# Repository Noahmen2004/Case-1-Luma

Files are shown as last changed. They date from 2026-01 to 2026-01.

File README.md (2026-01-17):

# Case-1-Luma
Case 1: Luma ontwerp slimme producten Ugent

# LUMA - Slim Fietsverlichtingssysteem

**Deze repository bevat de volledige broncode, specifiek geoptimaliseerd voor de Arduino Nano.**

**LUMA** is een geavanceerd, modulair en zelfvoorzienend verlichtingssysteem voor fietsen. Het combineert veiligheid met een duurzame, gerecyclede stroomvoorziening. Het systeem beschikt over dynamische richtingaanwijzers ("Audi-stijl"), een smelheids gestuurd remlicht en een unieke opstartanimatie.

Wat LUMA uniek maakt, is het **hybride stroomsysteem**: een hergebruikte DC-motor (uit een oude schuurmachine) fungeert als krachtige dynamo. Een speciaal circuit met een **buffercondensator** stabiliseert de energie om de centrale powerbank op te laden, die vervolgens de verlichting voedt en je smartphone kan opladen via USB-C.

## Functionaliteiten

### 1. Slimme Verlichting
* **Achterlicht (Matrix 3x12):**
    * **Rijden:** Gedimd rood licht.
    * **Vertragen (Uitbollen):** Licht op naar medium rood (gedetecteerd via accelerometer).
    * **Remmen:** Fel rood remlicht.
    * **Noodstop:** Knipperend rood licht (strobe) bij hard remmen.
* **Voorlicht (Matrix 3x8 + PowerLEDs):**
    * **Dagrijverlichting (DRL):** Witte LED-matrix voor zichtbaarheid.
    * **Koplamp:** 4x High Power LEDs voor zicht in het donker (geschakeld via MOSFET).
* **Richtingaanwijzers:**
    * Dynamische "Wipe" animatie (Oranje) die van binnen naar buiten loopt.

### 2. Modulair & Waterdicht Ontwerp
* **Waterdichte Connectoren:** Het systeem maakt gebruik van hoogwaardige IP68 connectoren (YETOR). Hierdoor is de opstelling volledig modulair: lampen en knoppen kunnen eenvoudig worden losgekoppeld of vervangen.
* **3D Geprinte Behuizing:** Op maat gemaakte behuizingen met **TPU-afdichtingen** zorgen ervoor dat de elektronica in alle weersomstandigheden droog blijft.

### 3. DIY Hybrid Power (Upcycled Dynamo)
* **Custom Generator:** Een DC-motor uit een oude schuurmachine is gemonteerd als wrijvingsdynamo.
* **Stabiele Stroom:** Een circuit met een grote **buffercondensator** vlakt het fluctuerende signaal van de motor af tot een constante 5V-lading voor de powerbank.
* **Phone Charging:** Geïntegreerde USB-C uitgang aan het stuur om je telefoon op te laden tijdens het fietsen.

## Hardware & Componenten

### Elektronica
* **Microcontroller:** Arduino Nano (Code in `/code`).
* **Sensor:** MPU-6050 Accelerometer (Op zijn zijkant gemonteerd).
* **Generator:** DC Motor (Gerecycled uit schuurmachine).
* **Power Conditioning:** Buffercondensator.
* **Opslag:** Powerbank met pass-through charging support.
* **LEDs:** WS2812B Strips + 4x High Power LEDs.
* **Bediening:** 3x R16-503 Latching Drukknoppen met LED-feedback.

### Connectiviteit
We gebruiken **YETOR Waterdichte Connectoren** om de centrale unit met de randapparatuur te verbinden.
* **Product:** [YETOR Waterdichte Draadconnectoren (Amazon)](https://www.amazon.nl/YETOR-waterdichte-draadconnectoren-vrachtwagen-draadverbindingen/dp/B07S7J85BT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)

## 3D Onderdelen (STL Bestanden)

Alle printbare onderdelen zijn te vinden in de map 3D- onderdelen. Het systeem maakt gebruik van een universele "Rekker & Haak" montagemethode.

### 1. Verlichtingsmodules
* Licht houder: Behuizing waar de LED-matrix in past.
* Licht lens: Transparante lens voor lichtdiffusie die op de houder klikt.

### 2. Centrale Control Unit
* Behuizing dynamo en powerbank: Behuizing voor de Arduino Nano, PCB en Powerbank.
* Dichtingsring: Een flexibele dichtingsring (**Print in TPU**) voor het waterdicht maken van de deksel.

### 3. DIY Dynamo Systeem
* Dynamo houder: Robuuste klem om de schuurmachine-motor aan de voor- of achtervork te bevestigen.
* Dynamo wiel: Een wrijvingswiel dat op de as van de DC-motor wordt geperst om contact te maken met de fietsband.

### 4. Bediening & Montage
* Knoppen behuizing: Behuizing voor de 3 knoppen aan het stuur.
* Bevestigings haak: Universele haak voor het montagesysteem.
* Aanpasbare rekker: Een flexibele, verstelbare rekker (**Print in TPU**) die om het fietsframe spant en in de haak grijpt.

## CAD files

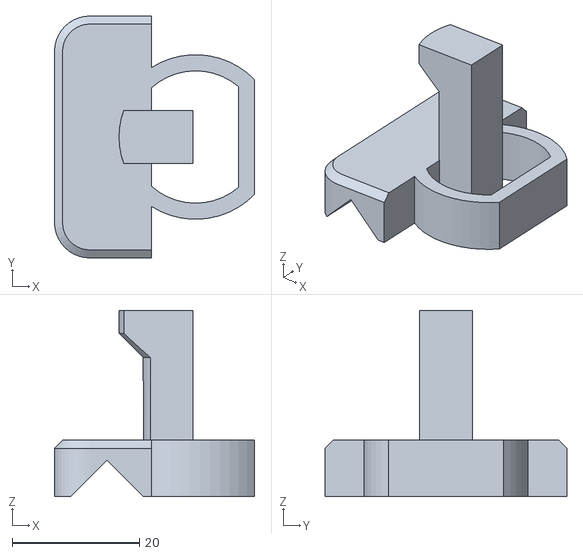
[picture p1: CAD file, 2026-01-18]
3D-onderdelen/GSM houder slider.stl
31.5 x 38.1 x 29.3

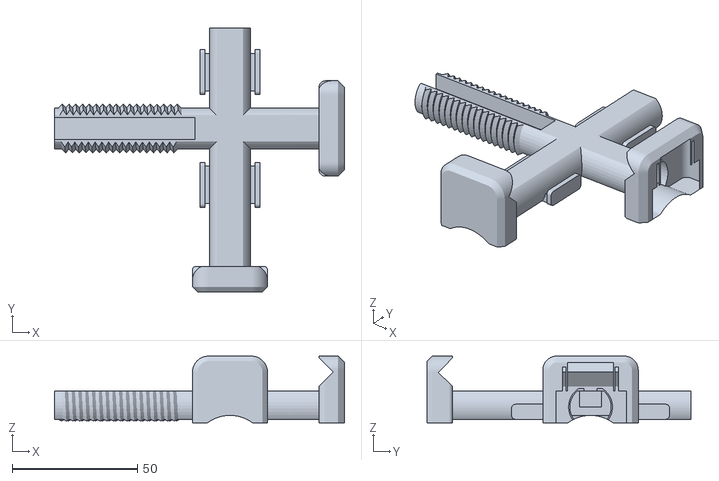
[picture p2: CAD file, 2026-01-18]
3D-onderdelen/GSM houder.stl
115.7 x 105.2 x 26.7

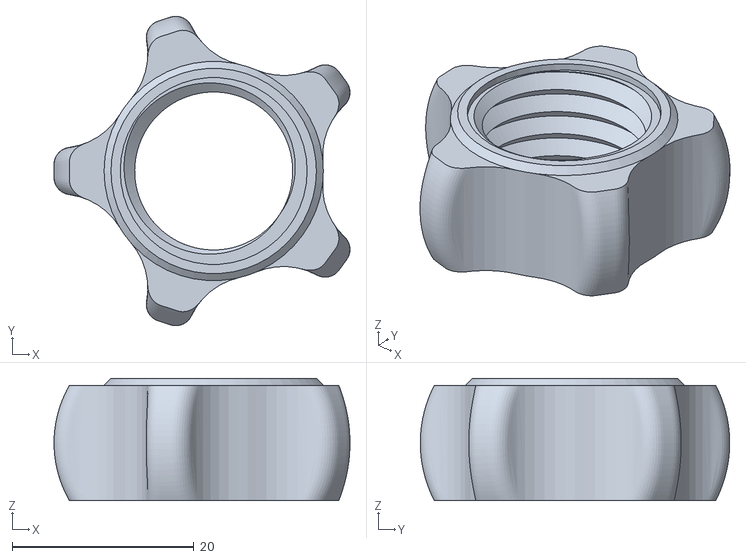
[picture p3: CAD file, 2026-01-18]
3D-onderdelen/GSM houder knob.stl
32.6 x 34.1 x 13.5

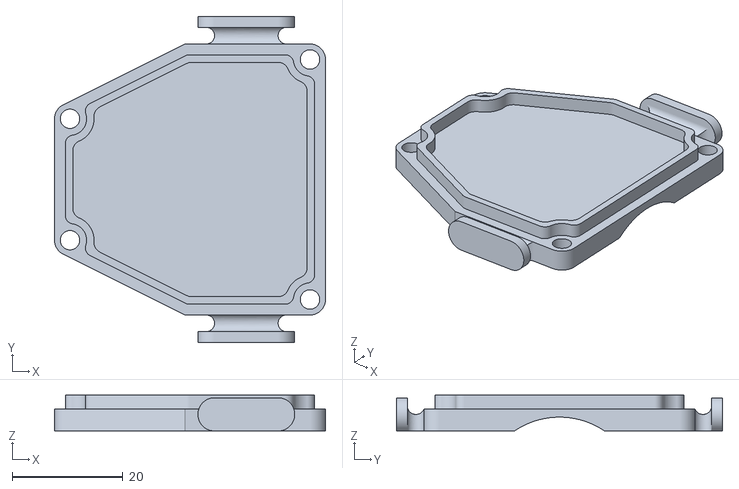
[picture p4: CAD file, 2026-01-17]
3D-onderdelen/Case drukknoppen male.stl
49.0 x 59.0 x 6.50

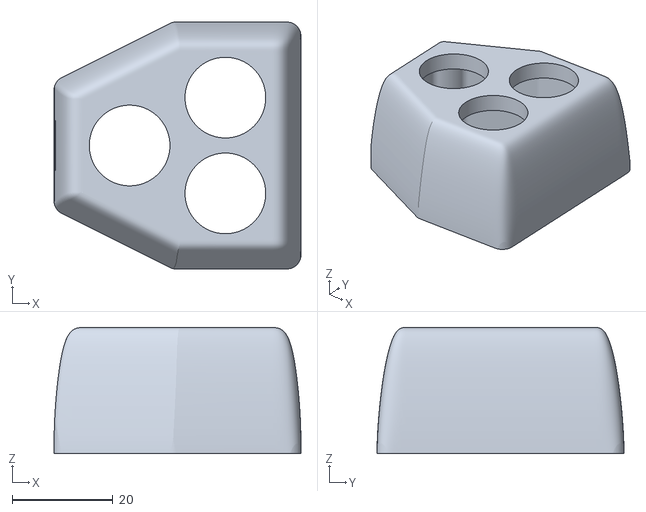
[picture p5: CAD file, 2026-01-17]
3D-onderdelen/Case drukknoppen female.stl
49.0 x 49.0 x 25.0

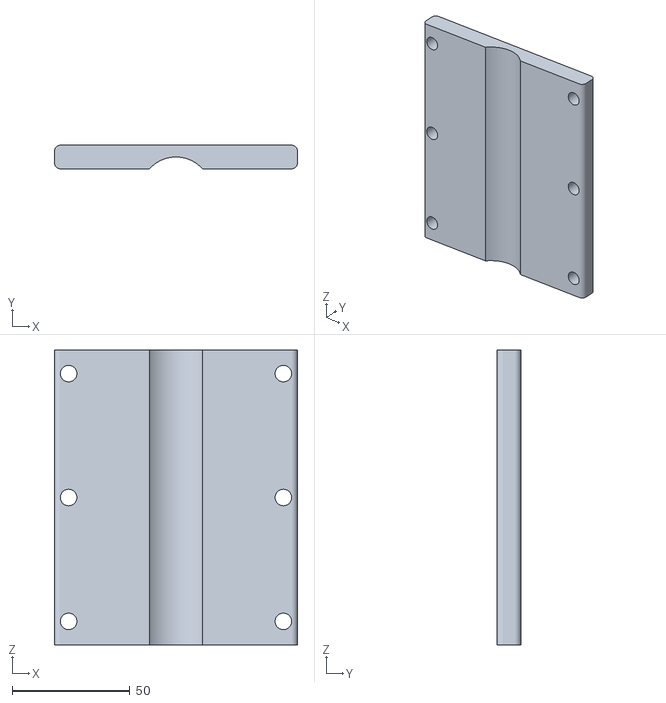
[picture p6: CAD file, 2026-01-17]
3D-onderdelen/bevestigingsplaat.stl
103.0 x 10.0 x 125.0

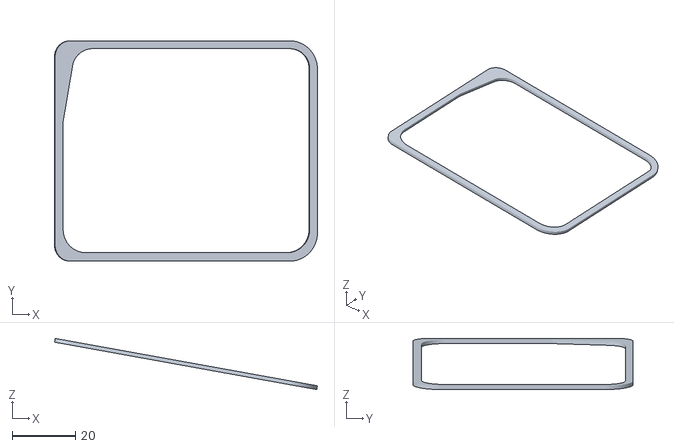
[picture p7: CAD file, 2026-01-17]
3D-onderdelen/tpu bandje.stl
83.2 x 69.7 x 16.2

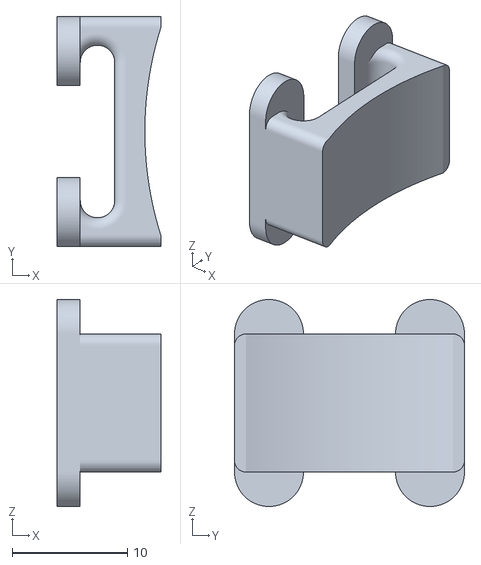
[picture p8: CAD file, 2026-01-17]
3D-onderdelen/klemeke-nieuw.stl
9.00 x 20.0 x 18.0

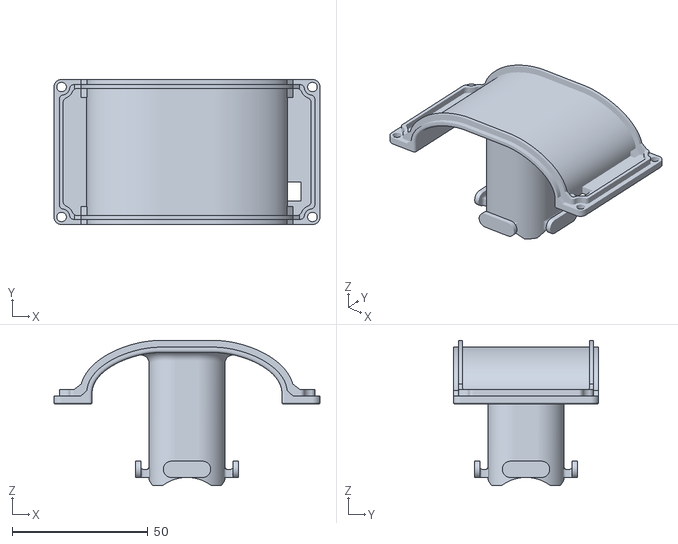
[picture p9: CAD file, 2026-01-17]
3D-onderdelen/achterlicht_houder_v5.stl
98.0 x 53.5 x 53.5

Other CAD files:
3D-onderdelen/Case drukknoppen.prt
3D-onderdelen/Dynamo wiel.prt
3D-onderdelen/achterlicht_v4.prt
3D-onderdelen/dynamohouder.prt
3D-onderdelen/omhulsel.prt
